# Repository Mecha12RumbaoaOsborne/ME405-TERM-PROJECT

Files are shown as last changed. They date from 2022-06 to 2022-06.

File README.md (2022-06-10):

# ME405-TERM-PROJECT
This repository contains the project files, source code, and other documents produced as part of the Polar Plotter project conducted 
by Ruodolf Rumbaoa and Barret Osborne. This project was done as part of the ME405 Mechatronics class for Cal Poly San Luis Obispo. The 
code included in this repository is ran on a NucleoL476RG that interfaces with two TMC4210 and two TMC2208 stepper drivers to control
two 4-wire NEMA 17 stepper motors. The baord also interfaces with a DC motor to control pen up/pen down functionality. 

One of the NEMA 17 steppers mount on a 3D printed structure that is mounted on a white board and a piece of 3/4 plywood. This stepper is
used to drvie the revolute motion of the plotter arm. The second stepper is used to drive the translation along the plotter's arm using a
belt and pulley system. The pen and DC motor are mounted on the arm and translates when the belt is driven by the second stepper motor. 
The arm sits on a lazy susan bearing. A wheel is also connected to the end of the arm to provide additional support. 

The TMC4210 driver class file is used to control the position or velocity of the steppers and can be
used for different functions like, enable/disable, position/velocity reading, taget position/velocity setting, zeroing, and homing. The
main routine uses a shceduler provided by the instructor of the class to run the tasks necessary to interpret an hpgl file stored in
board memory and draw it on a white board. Inkscape was used to generate an hpgl file from desired image files. When the main routine
is ran, the plotter waits for a button input to begin using the scheduler to parse the hpgl files for instructions and coordinates
which are then sent to the steppers as integer theta inputs. The plotter then draws the image point by point until it finishes. Finally,
when the drawing is finished the motors home to their original states. 

Demo Video:

ME405 DEMO (http://www.youtube.com/watch?v=i4va4gdoDfE "ME405 POLAR PLOTTER DEMO")

Documentation Page: [ME405 Polar Plotter Documentation](https://mecha12rumbaoaosborne.github.io/mecha12.github.io/)

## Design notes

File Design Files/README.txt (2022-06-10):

This folder contains all the mechanical design files for the polar plotter. These CAD files were made on SolidWorks 2022.

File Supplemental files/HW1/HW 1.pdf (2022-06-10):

Memorandum
To: Charlie Refvem
From: Ruodolf Rumbaoa
Date: 4/21/22

For the term project our driver must be able to interface with the TMC4210 and TMC2208 ICs to function properly with the stepper motor. Our drivers will need to have the functionality of enabling the TMC2208, setting velocity and acceleration on the TMC4210, setting a target position of the stepper through the TMC4210, and setting or reading the actual position of the stepper through TMC4210. These methods are laid out in the following class diagram.

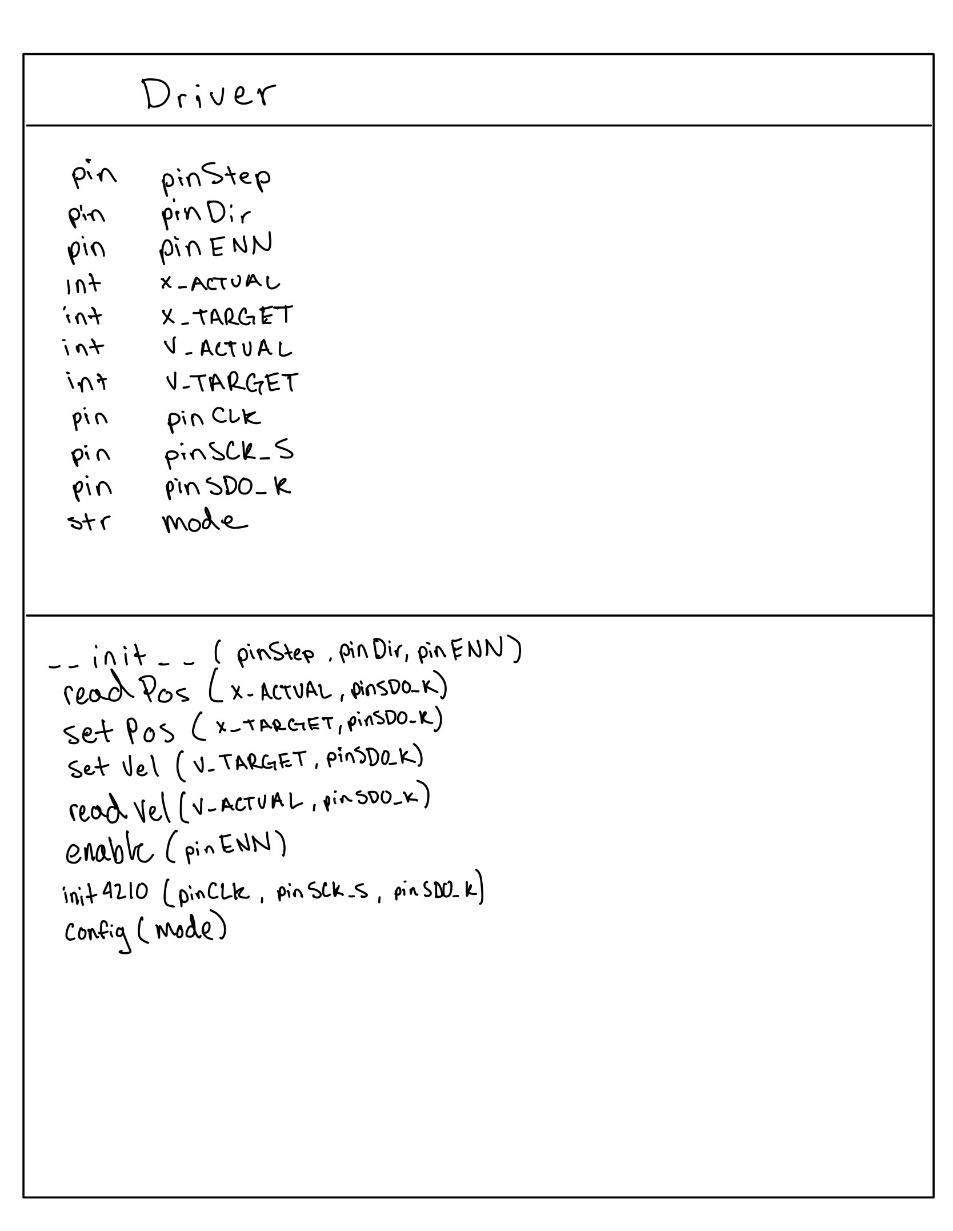
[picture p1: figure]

Figure 1. Driver class Diagram

To perform these methods, we must use the register map to either read or write to the corresponding register. To enable the TMC2208, we plan on connecting the EN1 and EN2 pins for the two TMC2208 drives to PC0 and PC1 on the Nucleo-L476RG, so that we can toggle them. These are read as active low, so we have to toggle the pin low to enable the TMC2208. To initialize the TMC4210 we write to the IF_CONFIGURATION_4210 address. Setting velocity will be done by writing to V_TARGET. Setting acceleration will be done by writing to A_MAX. To set a target position we will write to X_TARGET. Finally, to read the actual position of the stepper, we read from X_ACTUAL. We may also make use of limit switches to indicate the position of the stepper but have not figured out how to do that yet.

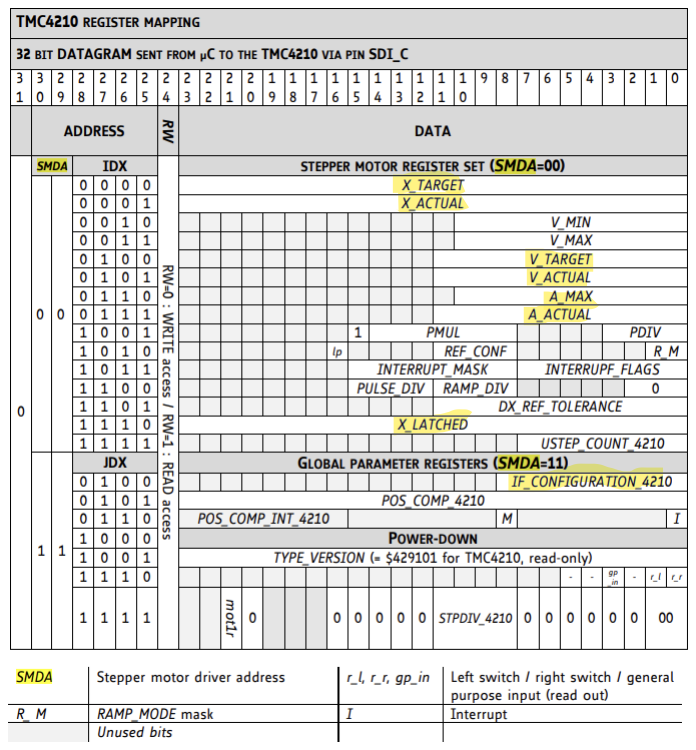
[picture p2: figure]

Figure 2. Register map for the TMC4210

The following table will include our initial plan for pin connections for the drivers with the Nucleo-L476RG. Most of the pins will be standard GPIOs while the MOSI, MISO, and SCK will be configured to a more dedicated pin.
Table 1. Preliminary pin configuration
MCU Pin | Function
PB_6 | CLK
PC2 | CS1
PC3 | CS2
PA_5 | SCK
PA_6 | MOSI
PA_7 | MISO
PC0 | EN1
PB4 | INDEX1
PC1 | EN2
PB5 | INDEX2
GND | GND
3V3 | +3.3V

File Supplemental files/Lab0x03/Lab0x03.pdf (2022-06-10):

### Memorandum

To: Charlie Refvem
From: Barrett Osborne, Ruodolf Rumbaoa
Date: 5/25/2021

For Lab 0x03, our task was to generate an HPGL file using Inkscape, save the file as a text file, and parse the contents of the text file. Our implementation began by separating the large string within the text file by semi-colons using split (‘;’). This resulted in a list of lists containing the strings of instructions and coordinates.

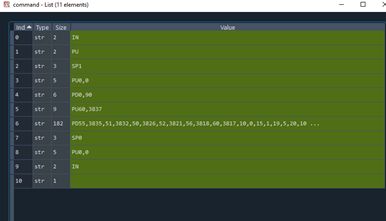
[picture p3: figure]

Figure 1. Data split by semi colons To interpret the instructions (pen up or pen down) we iterated through, looking at the first two characters of each element. By doing this we could interpret the instructions generated by Inkscape. We then stripped these instruction characters to generate an array of all the coordinates to be processed through our Newton Raphson code from HW2.

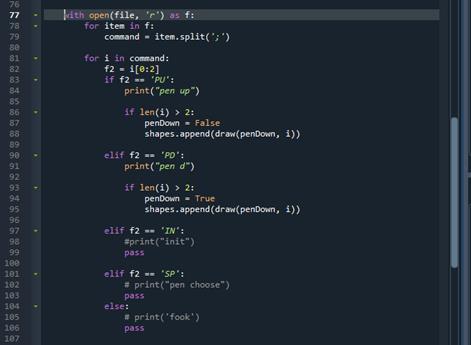
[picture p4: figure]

Figure 2. Instruction interpretation code snippet

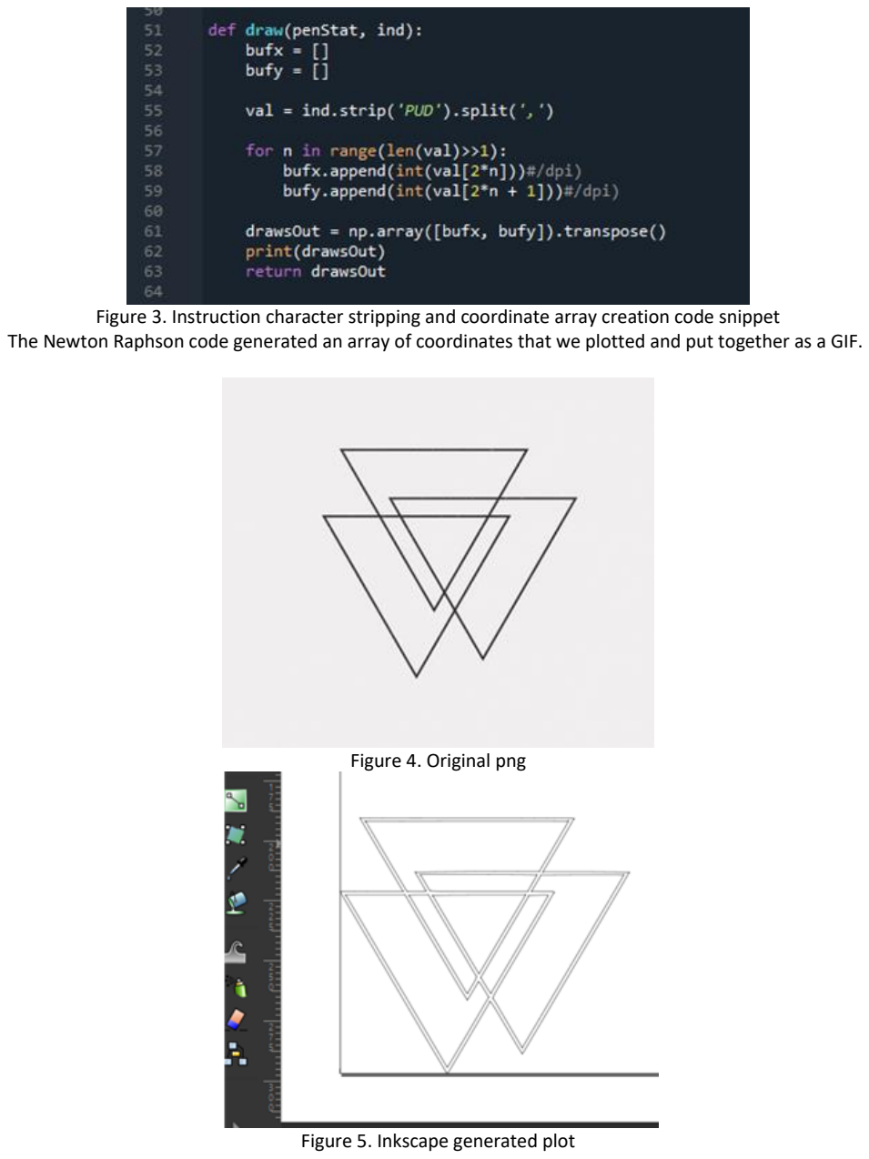
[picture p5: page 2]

Figure 3. Instruction character stripping and coordinate array creation code snippet The Newton Raphson code generated an array of coordinates that we plotted and put together as a GIF.

Figure 4. Original png

Figure 5. Inkscape generated plot

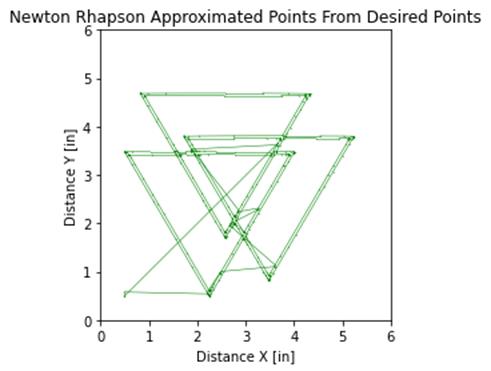
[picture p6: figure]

Figure 6. Plot generated from Newton Raphson code. NOTE: this plot and GIF shows the position of the end effector and doesn’t show the pen lifting or going down

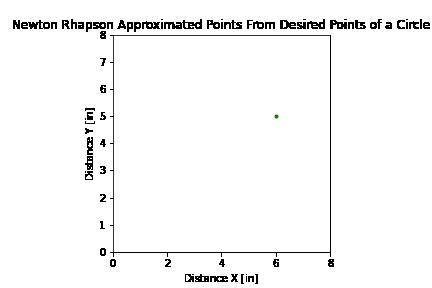
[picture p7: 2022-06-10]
Supplemental files/HW2/CirclePlot.gif

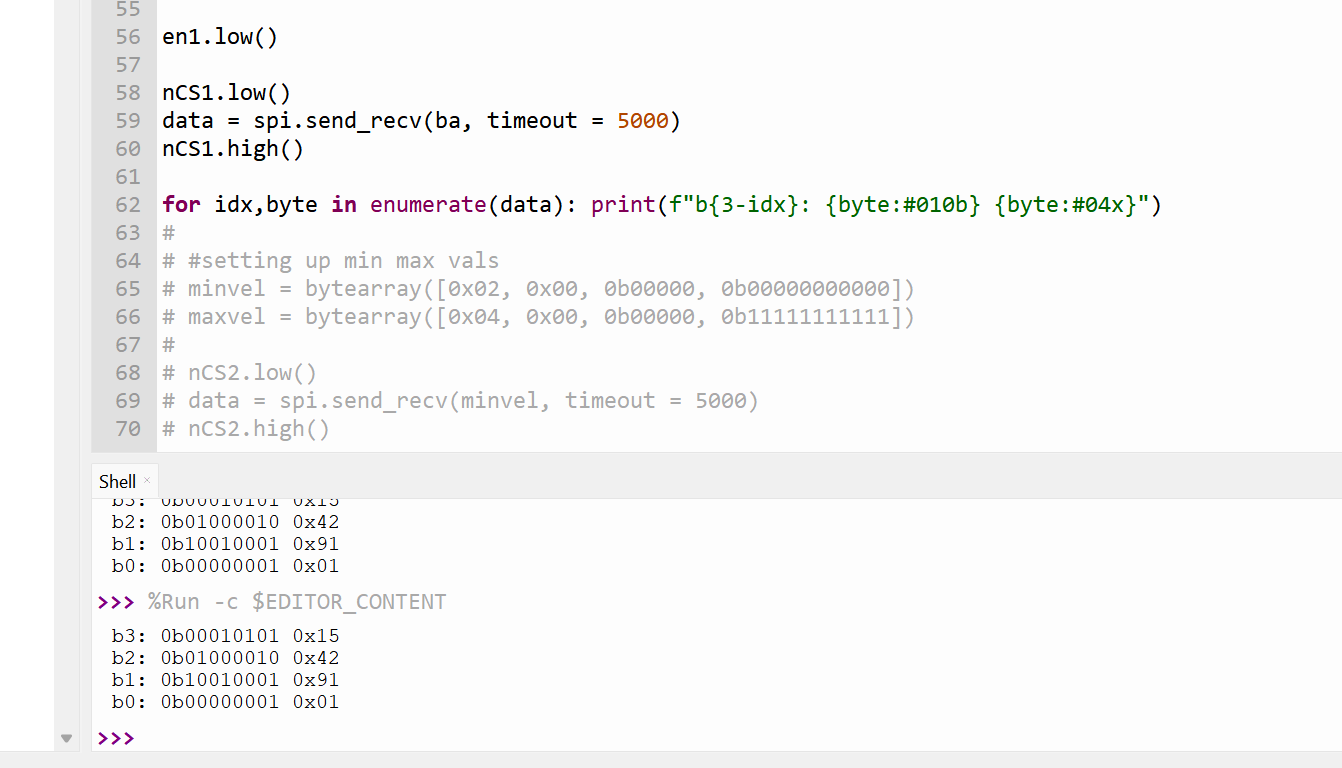
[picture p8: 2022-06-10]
Supplemental files/Lab0x02/typeregreadout.png

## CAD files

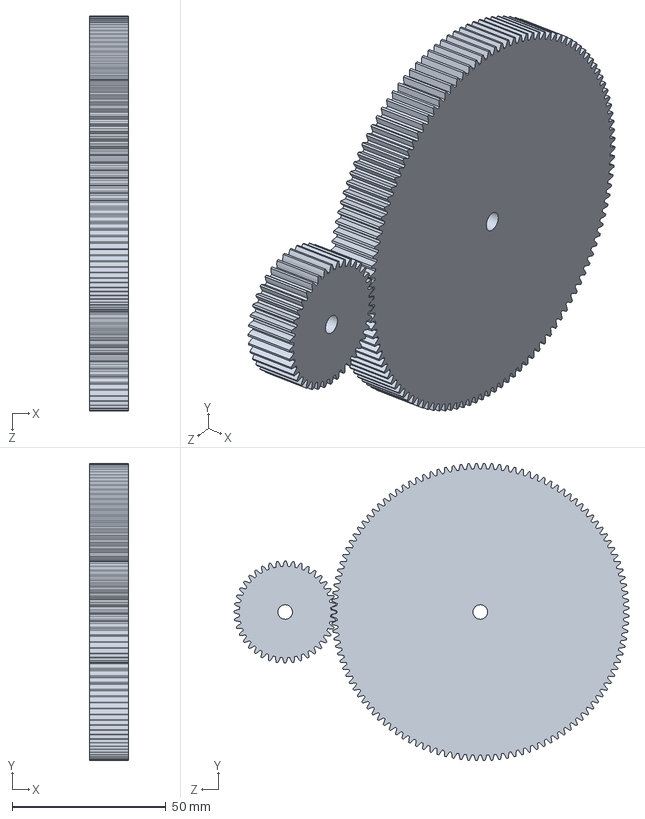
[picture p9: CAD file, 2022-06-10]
Design Files/Gears.SLDASM
12.7 x 96.8 x 128.6 mm
spur gear_ai x 2

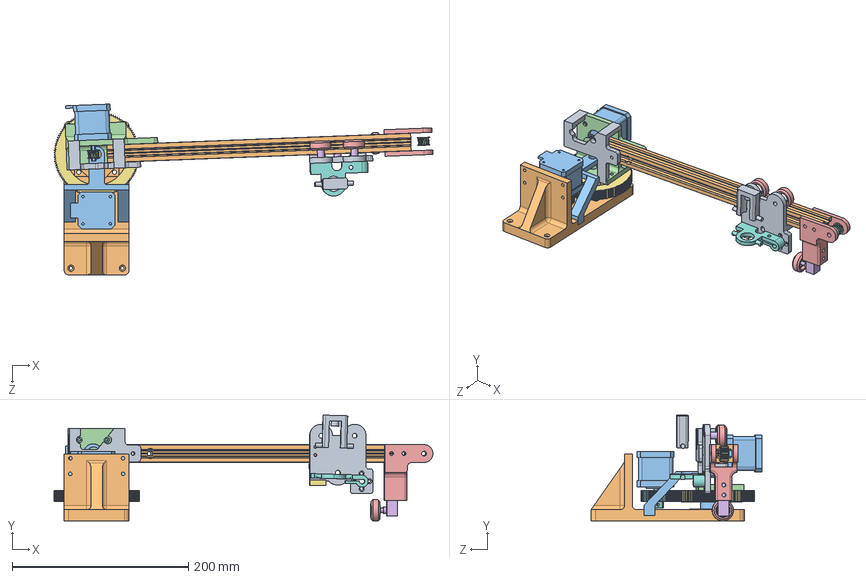
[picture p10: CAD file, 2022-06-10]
Design Files/Project Assembly.SLDASM
430.0 x 120.1 x 193.9 mm
Carriage Plate
2020 profile
40-42 motor x 2
2GT-pulley x 2
Rollers x 4
Spacers for rollers x 3
Hard Stop
PenArmNew
Motor box cageSLDPRT
baseplate without axel guard
BaseArm gaurd
Motor Box to go with cage bearing
NEW END BEAM
EndPlate Bearing
SpurGearBig
SmallGear2
SpringEnd
Bearingtop x 2
BearingCenter

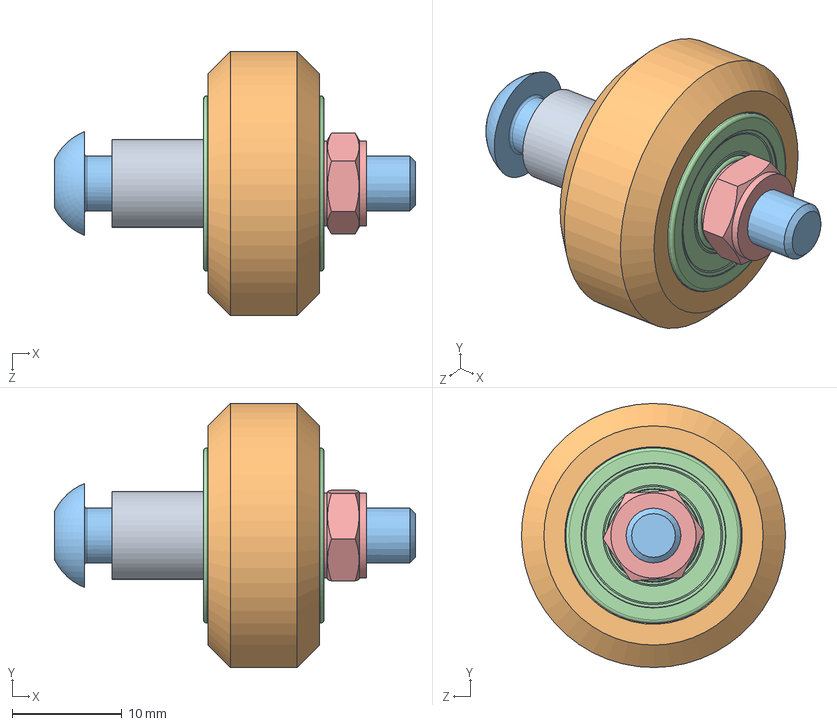
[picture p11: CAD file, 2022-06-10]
Design Files/ASM Roller X-Axis.SLDASM
33.0 x 24.1 x 24.1 mm
Spacers for rollers
Rollers
M5X30 Pan Head Screw
625pillow x 2
M5 Self-locking nut

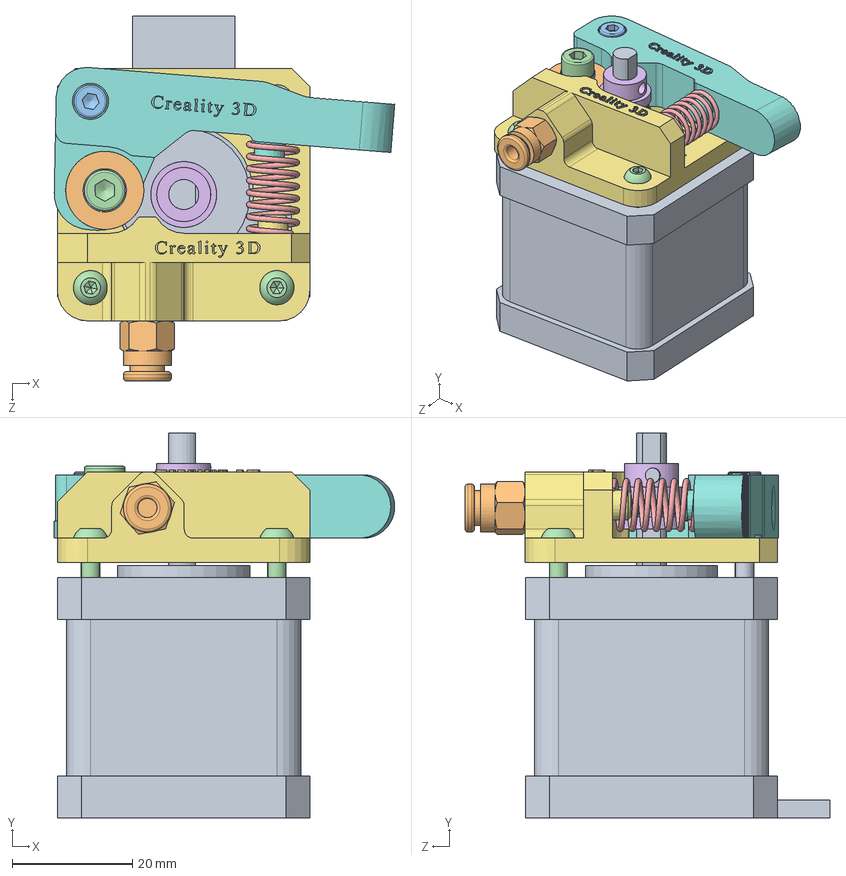
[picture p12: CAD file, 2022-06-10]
Design Files/ASM Extruder.SLDASM
56.7 x 64.0 x 60.7 mm
40-42 motor
624U pillow
M3X18 Socket Head Screw
M3X10 Pan Head Screw x 2
Extrusion Spring
E gear
E housing 2
E idler tensioner
M3X10 Flush Head Screw
M6 Pneumatic joint
M4 Split Washer
M4X8 Socket Head Screw

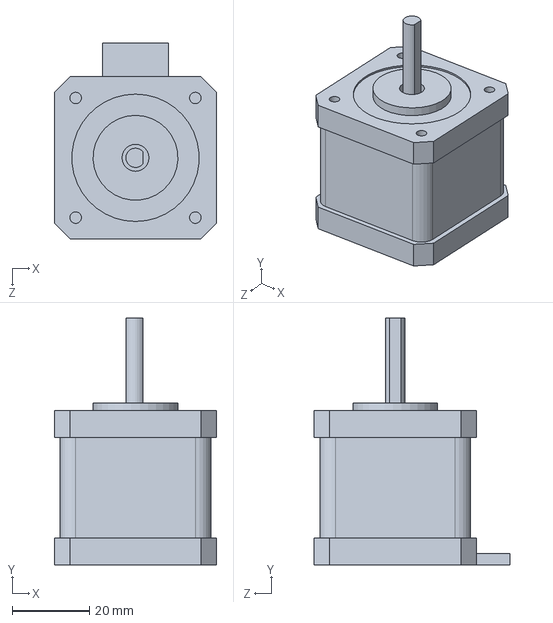
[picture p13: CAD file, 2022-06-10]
Design Files/40-42 motor.SLDPRT
42.0 x 64.0 x 50.7 mm

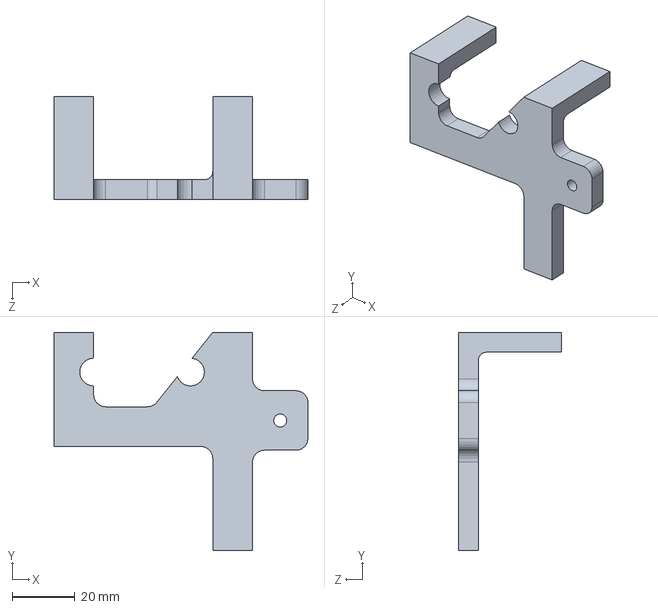
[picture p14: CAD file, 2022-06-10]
Design Files/Motor box cageSLDPRT.SLDPRT
81.3 x 69.8 x 32.9 mm

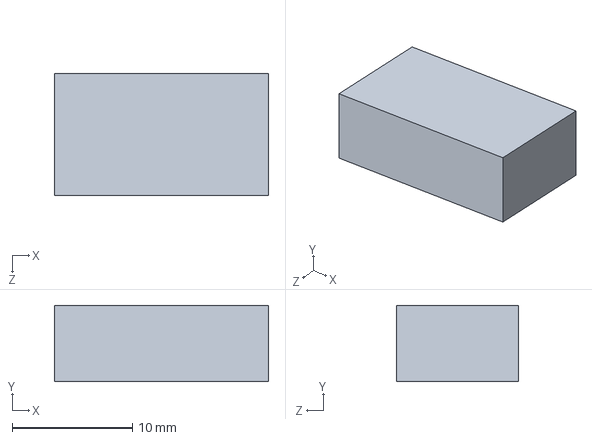
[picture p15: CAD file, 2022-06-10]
Design Files/Hard Stop.SLDPRT
17.8 x 6.35 x 10.2 mm

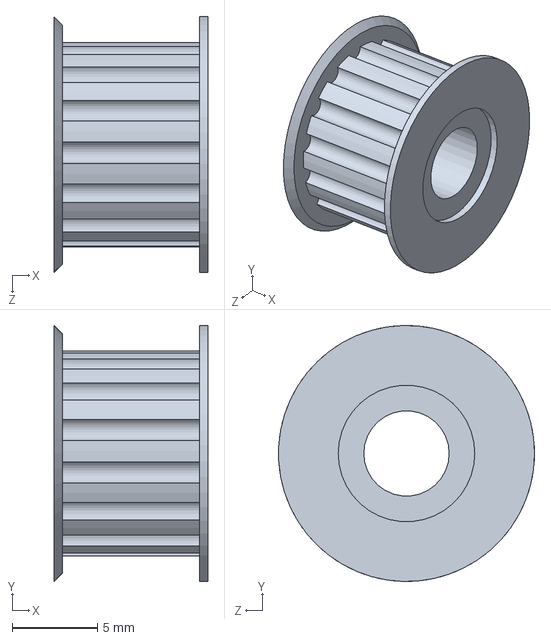
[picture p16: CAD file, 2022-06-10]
Design Files/2GT-pulley.SLDPRT
9.00 x 15.0 x 15.0 mm

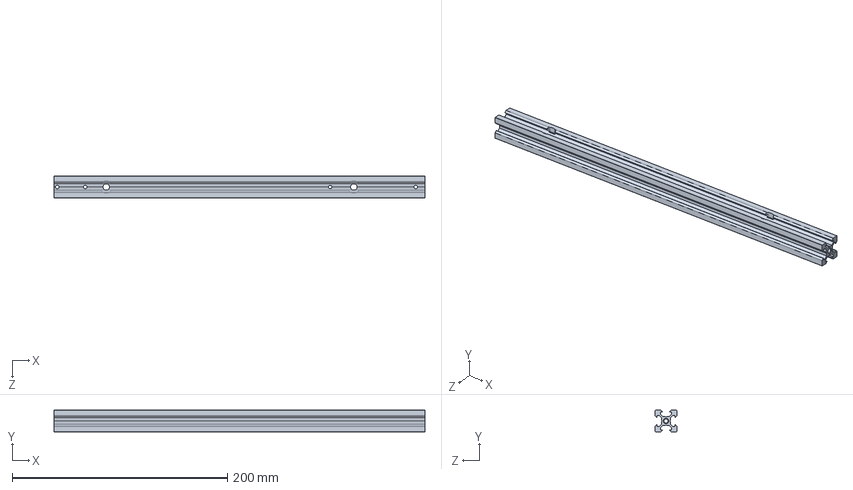
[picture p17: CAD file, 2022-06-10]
Design Files/2020 profile.SLDPRT
345.0 x 20.0 x 20.0 mm

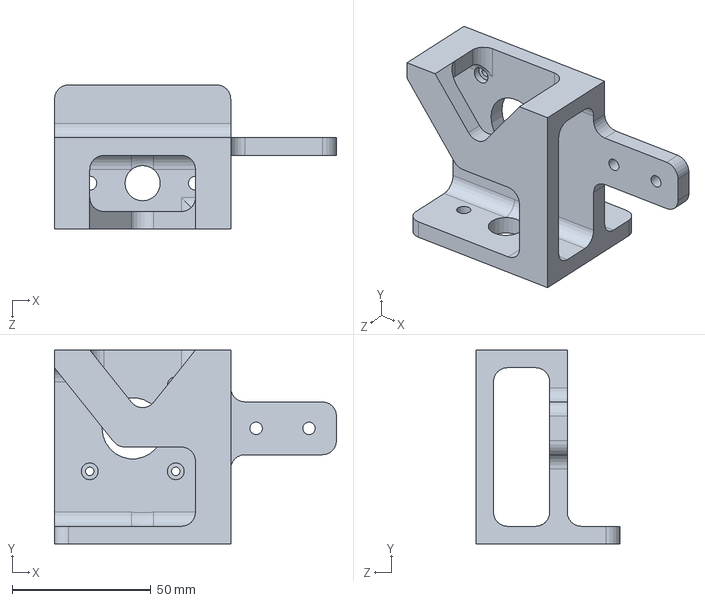
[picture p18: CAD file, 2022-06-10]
Design Files/Motor Box1.SLDPRT
101.6 x 69.8 x 52.0 mm

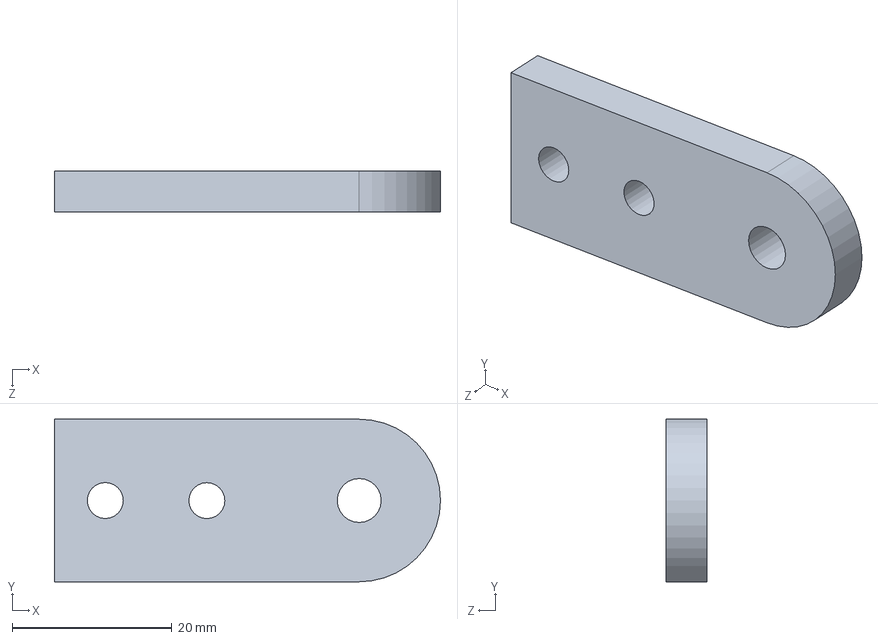
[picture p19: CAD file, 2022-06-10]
Design Files/End Plate.SLDPRT
48.3 x 20.3 x 5.08 mm

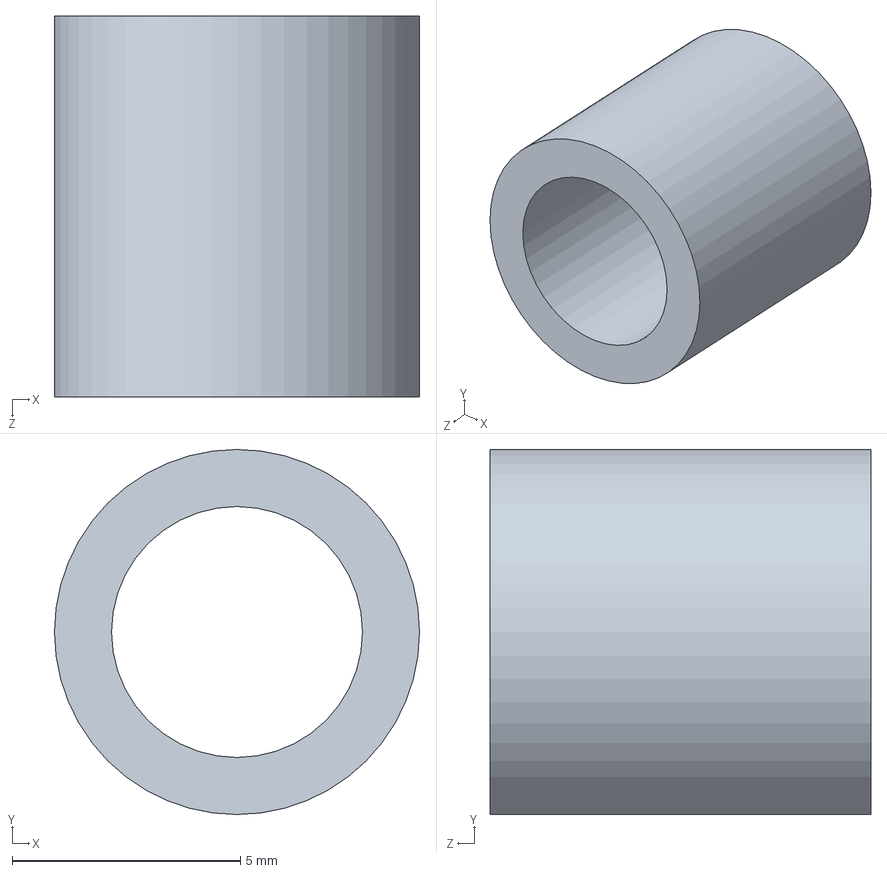
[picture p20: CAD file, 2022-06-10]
Design Files/Spacers for rollers.SLDPRT
8.00 x 8.00 x 8.35 mm

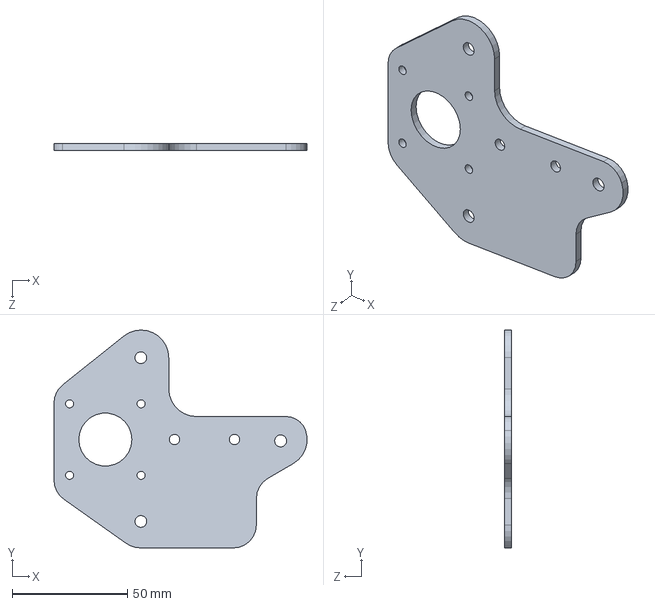
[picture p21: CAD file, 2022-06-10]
Design Files/X motor bracket.SLDPRT
109.7 x 94.5 x 3.00 mm

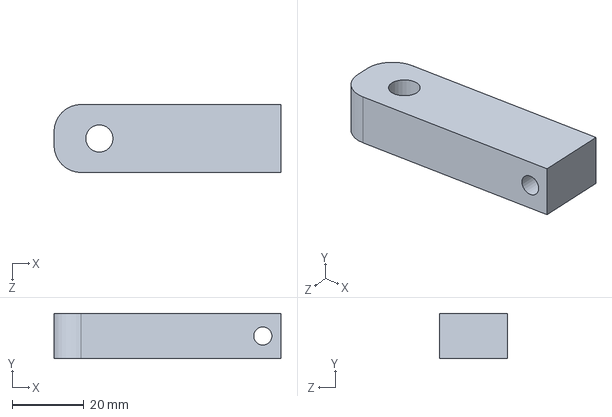
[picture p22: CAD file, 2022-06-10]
Design Files/Pen Arm.SLDPRT
63.5 x 12.7 x 19.1 mm

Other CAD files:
Design Files/PenArmNew.SLDPRT
Design Files/Radial Gearbox.SLDPRT
Design Files/Rollers.SLDPRT
Design Files/Motor Box to go with cage bearing.SLDPRT
Design Files/2020-2 profile.SLDPRT
Design Files/ASM X-Roller Bolt.SLDASM
Design Files/BaseArm gaurd.SLDPRT
Design Files/Baseplate spacer.SLDPRT
Design Files/BearingCenter.SLDPRT
Design Files/Bearingtop.SLDPRT
Design Files/Carriage Plate unbent.SLDPRT
Design Files/Carriage Plate.SLDPRT
Design Files/DrivenGearWithHoles.SLDPRT
Design Files/DrivingGear.SLDPRT
Design Files/E plate.SLDPRT
Design Files/End Plate 2.SLDPRT
Design Files/EndPlate Bearing.SLDPRT
Design Files/Gear1 hub.SLDPRT
Design Files/Gear2 hub.SLDPRT
Design Files/Motor Box to go with cage.SLDPRT
Design Files/Motor Box.SLDPRT
Design Files/NEW END BEAM.SLDPRT
Design Files/Roller bushing.SLDPRT
Design Files/SmallGear.SLDPRT
Design Files/SmallGear2.SLDPRT
Design Files/Spring Pegs.SLDPRT
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

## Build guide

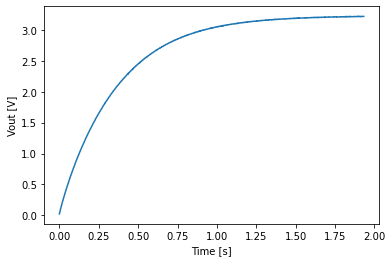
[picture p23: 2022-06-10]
Supplemental files/Lab0x00/5 working mostly/step response plot.png

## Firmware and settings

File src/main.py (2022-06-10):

"""!@file main.py
@brief      Main file for polar plotter project.
@n
@page mainroutine  main.py
@brief      This main routine makes use of the provided scheduler to run the parsing
            of an hpgl file saved in baord memory, and sending insturctions(pen up/down)
            and coordinates to the plotter.
@details    When ran, the main routine waits for the user to press the blue button on the 
            NucleoL476RG board. Once this press is detected, the scheduler runs the parsing
            and drawing task to extract instructions and coordinates from the hpgl file.
            The instructions are interpreted as pen up/down and the DC motor actuates
            according to it. The xy coordinates are converted to theta 1 and theta 2 values
            sento to the repective stepper. Once the task finishes a flag is raised and 
            the steppers go back to home position. 
@n     
Source Folder
    [https://github.com/Mecha12RumbaoaOsborne/ME405-TERM-PROJECT]
@n

@author Barret Osborne
@author Ruodolf Rumbaoa
@date 06/09/2022

"""
from ulab import numpy as np
#import numpy as np
import cotask, task_share, gc, array
from time import sleep
from math import cos, sin, pi, tan, sqrt, acos, asin, atan2
from pyb import SPI, Pin, Timer, ExtInt, UART
from TMC4210 import TMC4210drv

def onButtonpress(IRQ_src):
    '''
    @breif Button flag used to start the drawing task
    '''
    buttonFlag.put(1)
    
def g(x, theta, r):
    '''
    @breif Calculates motor thetas from xy coordinate inputs
    '''
    g1 = x[0]-r*theta[1]*float(cos(theta[0])) 
    g2 = x[1]-r*theta[1]*float(sin(theta[0]))
    return np.array([g1, g2])

def dg_dtheta(theta, r):
    '''
    @breif Calculates the jacobian
    '''
    return np.array([[r*theta[1]*float(sin(theta[0])), -r*float(cos(theta[0]))],
                            [-r*theta[1]*float(cos(theta[0])), -r*float(sin(theta[0]))]]) 

def NewtonRaphson (fcn, jacobian, guess, thresh):
    '''
    @breif Calculates the new thetas approximated by NewtonRaphson method
    '''
    new_theta = guess - (np.dot(np.linalg.inv(jacobian),fcn))
    return new_theta

def iterate(fcn, x, theta, r, thresh):
    '''
    @breif Used to iteratively call NewtoRaphson method to find motor thetas
    '''
    while True:
        newTheta = fcn(g(x, theta, r), dg_dtheta(theta, r), theta, thresh)
        gtheta = g(x, theta, r)
    
        if np.linalg.norm(gtheta) > thresh:
            theta = newTheta
            continue
        else:
            correct_theta = newTheta
            break
    return correct_theta

def parse(file):
    '''
    @breif Opens the hpgl file defined and extracts pen up/down instructions
           and xy coordinates of each point
    @param file The hpgl file to be prsed
    '''
    with open(file, 'r') as f:
        for item in f:
            command = item.split(';')
        for i in command:
            f2 = i[0:2]
            if f2 == 'PU':
                if len(i) > 2:
                    shapes.append(extract(i))
            elif f2 == 'PD':
                if len(i) > 2:
                    shapes.append(extract(i))
            else:
                pass
            f.close() 
            shapesInst = shapes
    return shapesInst

def extract(insts):
    '''
    @breif Splits extracted instructions by commas to generate xy coordinates
    @param insts Instructions extracted from parsed file
    '''
    instOut = []
    val = insts.split(',')

    for n in range(len(val)>>1):    
       instOut.append([val[2*n], val[2*n+1]])
       

    return instOut

def drawTask ():
    '''
    @breif Calls the draw function and sets flag to represent when drawing is finished
    '''
    while True:
        print('DRAWING')
        xcoordData.clear()
        ycoordData.clear()
        instructions = parse(file)
        for point in instructions:
            draw(point) 
        drawingDone.put(1)
        buttonFlag.put(0)
        state == 0
        break
    yield state
        
def draw(instVal):
    '''
    @breif Uses the extracted xy coordinates to calculate motor thetas. Then sends
           motor thetas to respective stepper. Also interprets pen instructions to 
           actuate DC motor.
    '''
    inst = instVal[0]
    k=0
    if inst[0][0:2] == 'PU':
        print('pen up')
        PB5.low()
        PB4.high()
        sleep(.8)
        
        
        instVal[0][0] = instVal[0][0].strip('PU')
        
        #Construct as a share later 0 = up 1 = down 
        penShare = 0
        
        while k < len(instVal):
            incoordx = 1.5*((int(instVal[k][0])+100)/dpi)
            incoordy = 1*((int(instVal[k][1])+1)/dpi)
            xcoordData.put(incoordx)
            ycoordData.put(incoordy)
            uart2.write(f'{xcoordData.get()}, {ycoordData.get()}\r\n')
            hyp = sqrt(incoordx**2 + incoordy**2)
            
            thetas = np.array([1*(atan2(incoordy,incoordx)), hyp/inrad])
            
            usteps1 = int(thetas[0]*3600/(2*pi))
            usteps2 = int(thetas[1]*400/(2*pi))
            print(f'[{usteps1}, {usteps2}]')
            
            while True:
                stepthresh = 1
                drv1.setPos(usteps1)
                drv2.setPos(usteps2)
                sleep(.25)
                comp1 = usteps1
                comp2 = usteps2
                act1 = drv1.getPos()
                act2 = drv2.getPos()
                
                if (abs(comp1 - act1) < stepthresh) and (abs(comp2 - act2 < stepthresh)):
                    break

                else:
                    pass
                    
            k+=1
            continue
            
        
    elif inst[0][0:2] == 'PD':
        print('pen down')
        PB4.low()
        PB5.high()
        instVal[0][0] = instVal[0][0].strip('PD')
        
        #Construct as a share later 0 = up 1 = down 
        penShare = 1
        
        while k < len(instVal):
            incoordx = 1.5*((int(instVal[k][0])+100)/dpi)
            incoordy = 1*((int(instVal[k][1])+1)/dpi)
            xcoordData.put(incoordx)
            ycoordData.put(incoordy)
            uart2.write(f'{xcoordData.get()}, {ycoordData.get()}\r\n')

            hyp = sqrt(incoordx**2 + incoordy**2)
            
            thetas = np.array([1*(atan2(incoordy,incoordx)), hyp/inrad])
            
            usteps1 = int(thetas[0]*3600/(2*pi))
            usteps2 = int(thetas[1]*400/(2*pi))
            print(f'[{usteps1}, {usteps2}]')

            while True:
                stepthresh = 1
                drv1.setPos(usteps1)
                drv2.setPos(usteps2)
                sleep(.25)
                comp1 = usteps1
                comp2 = usteps2
                act1 = drv1.getPos()
                act2 = drv2.getPos()
                
                if (abs(comp1 - act1) < stepthresh) and (abs(comp2 - act2 < stepthresh)):
                    break

                else:
                    pass
            k+=1
            continue
            

    else:
        while k < len(instVal):
            incoordx = .7*((int(instVal[k][0])+100)/dpi)
            incoordy = 1*((int(instVal[k][1])+1)/dpi)
            xcoordData.put(incoordx)
            ycoordData.put(incoordy)
            uart2.write(f'{xcoordData.get()}, {ycoordData.get()}\r\n')
            hyp = sqrt(incoordx**2 + incoordy**2)

            thetas = np.array([1*(atan2(incoordy,incoordx)), hyp/inrad])
            
            usteps1 = int(thetas[0]*3600/(2*pi))
            usteps2 = int(thetas[1]*400/(2*pi))
            print(f'[{usteps1}, {usteps2}]')
            
            while True:
                stepthresh = 1
                drv1.setPos(usteps1)
                drv2.setPos(usteps2)
                sleep(.25)
                comp1 = usteps1
                comp2 = usteps2
                act1 = drv1.getPos()
                act2 = drv2.getPos()
                
                if (abs(comp1 - act1) < stepthresh) and (abs(comp2 - act2 < stepthresh)):
                    break
                    #sleep(.5)
                    pass

                else:
                    pass
            k+=1
            continue
    
    pass
if __name__ =='__main__':    
    state = 0 #INIT AND WAIT STATE
    
    #Limit switch pen up/down
    PC4 = Pin(Pin.cpu.C4, mode=Pin.OUT_PP, value=0)
    PB4 = Pin(Pin.cpu.B4, mode=Pin.OUT_PP, value=0)
    PB5 = Pin(Pin.cpu.B5, mode=Pin.OUT_PP, value=0)

    
    # Motor stuff
    drv1 = TMC4210drv(2, SPI.SLAVE, 1_000_000, 1, 1, None, Pin(Pin.cpu.C3, mode=Pin.OUT_PP, value =1), 4, 1, Pin(Pin.cpu.B6, mode = Pin.OUT_PP), Pin(Pin.cpu.C2, mode=Pin.OUT_PP, value =1))
    drv2 = TMC4210drv(2, SPI.SLAVE, 1_000_000, 1, 1, None, Pin(Pin.cpu.B0, mode=Pin.OUT_PP, value =1), 4, 1, Pin(Pin.cpu.B7, mode = Pin.OUT_PP), Pin(Pin.cpu.C0, mode=Pin.OUT_PP, value =1))
    
    uC = SPI(2)
    uC.init(SPI.MASTER, baudrate=1_000_000, phase=1, polarity=1, crc=None)
    
    #Set ensd to 1 for both drivers
    drv1.enable()
    drv2.enable()
   
    drv1.setRampmode()
    drv2.setRampmode()
    
    #Set VMIN
    drv1.setMinVel(0b00000000001)
    drv2.setMinVel(0b00000000001)
    
    #Set VMAX
    drv1.setMaxVel(0b00000000001)
    drv2.setMaxVel(0b00000000001)
    
    #Set Pulse div and ramp div
    drv1.setPulseramppulsediv(0b0000, 0b0000)
    drv2.setPulseramppulsediv(0b0000, 0b0000)
    
    #Set AMAX
    drv1.setMaxAcc(0b00000111,0b11010000)
    drv2.setMaxAcc(0b00000111,0b11010000)

    #Set PDIV 1 and PMUL 249
    drv1.setPMULPDIV(0b11111001, 0b0000001)
    drv2.setPMULPDIV(0b11111001, 0b0000001)
    
    #Start calib
    drv1.zeroHere()
    drv2.zeroHere()
    
    #UART Stuff
    uart2 = UART(2)
    uart2.init(115200, bits=8, parity=None, stop=1)
    
    #NewtonRaphson params
    theta_guess = np.array([5,6])
    thresh = 1e-6
    r = 0.24
    inrad = r/(pi*2)
    
    #HPGL params
    shapes = []
    
    #Name the file to be parsed and drawn, specify dpi set from Inkscape. Increaseing or decreasing
    #will change the actual size of drawing on the baord 
    file = "susamongus.hpgl"
    dpi = 240
    
    # Coop task shares and queues
    
    #used as a flag for knowing when the drawing task has finished
    drawingDone = task_share.Share ('i', thread_protect = False, name = "drawingDone")
    
    #Making use of the button on the Nucleo board to start the drawing task when pressed
    button_int = ExtInt(Pin.cpu.C13, ExtInt.IRQ_FALLING, Pin.PULL_NONE, None)
    button_int = ExtInt(Pin.cpu.C13, ExtInt.IRQ_FALLING, Pin.PULL_NONE, callback=onButtonpress)
    buttonFlag = task_share.Share ('i', thread_protect = False, name = "buttonFlag")
    
    #Set as 0 initially 
    buttonFlag.put(0)
    drawingDone.put(0)
    
    #Creating tasks
    drawTask = cotask.Task(drawTask, name = 'Task_2', priority = 1, 
                         period = 50, profile = True, trace = False)
    
    #Appending task to task list to be ran by scheduler based on priority
    cotask.task_list.append(drawTask)
     
    xcoordData = task_share.Queue ('f', 300, thread_protect = True, overwrite = False,
                           name = "xcoordData")
    ycoordData = task_share.Queue ('f', 300, thread_protect = True, overwrite = False,
                           name = "ycoordData")
    
    #Memory cleaning before running
    gc.collect ()
    xcoordData.clear()
    ycoordData.clear()

    #Run tasks using cotask when button is pressed. Stops the run if interrupted using ctrl+c
    while True:
        try:
            if buttonFlag.get() == 1:
                cotask.task_list.pri_sched()
            elif drawingDone.get() == 1:
                xcoordData.clear()
                ycoordData.clear()
                drv1.disable()
                drv2.disable()
                break
                
            else:
                pass
            
        except KeyboardInterrupt:
            drv1.disable()
            drv2.disable()
            PB5.low()
            break
    
    #Once the task finishes the scheduler stops being used and the motors home back to zero
        
    drv1.goZero()
    drv2.goZero()
    
    sleep(5)
    drv1.disable()
    drv2.disable()
    print('motors disabled')

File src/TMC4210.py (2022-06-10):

"""!@file TMC4210.py
@brief      Class file for stepper drivers.
@n
@page driver  TMC4210.py
@brief      This class file contains the methods and attributes of the TMC4210 drivers.
@details    The file includes methods for setting target position/velocity, reading 
            position/velocity, writing to configuration adresses, and homing/zeroing
            the stepper motors.. 

Source Folder
    [https://github.com/Mecha12RumbaoaOsborne/ME405-TERM-PROJECT]
@n

@author Barret Osborne
@author Ruodolf Rumbaoa
@date 06/09/2022

"""
from pyb import SPI, Pin, Timer
import time

# Stepper Register Set
#X_TARGET and V_TARGET (1 byte size) are made as bytes to be concatenated
#with integer values that the user inputs which are then turned to
#bytes objects (3 bytes size) to create a proper 32 bit datagram.
#Other adresses are hex values inputed into a bytearray with specific
#binary data to configure devices. SEE  TMC4210 data sheet for register info.

X_TARGET             = (0x00).to_bytes(1, 'big')
X_ACTUAL             = 0x02
V_MIN                = 0x04
V_MAX                = 0x06
V_TARGET             = (0x08).to_bytes(1, 'big')
V_ACTUAL             = 0x0A
A_MAX                = 0x0C
A_ACTUAL             = 0x0E
PMUL_PDIV            = 0x12
RAMPMODE_REFCONF     = 0x14
INTERRUPT_MASK_FLAGS = 0x16
PULSE_DIV_RAMP_DIV   = 0x18
DX_REF_TOLERANCE     = 0x1A
X_LATCHED            = 0x1C
USTEP_COUNT_4210     = 0x1E

# Global Parameter regs
IF_CONFIGURATION_4210= 0x68
POS_COMP_4210        = 0x6A
POS_COMP_INT_4210    = 0x6C
POWER_DOWN           = 0x70
TYPE_VERSION         = 0x73
REFERENCE_SWITCHES   = 0x7C
GLOBAL_PARAMETERS    = 0x7E
# R = 1 W = 0

class TMC4210drv:
    
    def __init__(self, spi_num, spi_mode, spi_baud, spi_phase, spi_pol, spi_crc, ncsPin, clk_timer, clk_channel, clkPin, ENPin):
        '''
        @brief      Initializes the drviver objects.
        @details    The driver objects are initialized as SPI2 peripherals with 
                    pin objects for clock timer/channel and enable PIN.
        @param spi_num SPI bus to initialize the driver (using SPI2)
        @param spi_mode SPI.PERIPHERAL
        @param spi_baud Baudrate for SPI transmission (using 1_000_000).
        @param spi_phase spi_pol These parameters dictate the mode being ran (using mode 3)
        @param spi_crc None
        @param ncsPin Pin object used for chip select
        @param clk_timer Timer object being used by drivers
        @param clk_channel Timer channel
        @param clkPin Pin object being used for clock signal 
        @param ENPin Pin object used for EN
        '''
        #use spi(2)
        self.spi = SPI(spi_num)
        
        #use params: SPI.SLAVE, 1000000, 1, 1, None 
        self.spi.init(spi_mode, baudrate=spi_baud, phase=spi_phase, polarity=spi_pol, crc=spi_crc)
        
        #use C3 or B0 for CS pins
        self.nCS = Pin(ncsPin, mode = Pin.OUT_PP, value = 1)
        
        #use C2 or C0 for EN pins
        self.EN = Pin(ENPin, mode = Pin.OUT_PP, value = 0)
        
        #use Timer(4)
        self.clk = Timer(clk_timer)
        
        #20 mHz timer
        self.clk.init(prescaler = 0, period =3)
        
        # need PWM mode pin PB6 for clkPin
        self.clk.channel(clk_channel, mode=Timer.PWM, pin = clkPin, pulse_width = 2)
        
        pass
       
    def enable(self):
        '''
        @brief enables the stepper
        '''
        #Sets en_sd bit to 1
        enableba = bytearray([IF_CONFIGURATION_4210, 0x00, 0x00, 0x20])
        
        #Set enable pin low to activate power to motor
        self.EN.low()
        
        self.nCS.low()
        self.spi.send_recv(enableba, timeout=2000)
        self.nCS.high()
        print('The motor is enabled.')
        
        pass
    
    def setRampmode(self):
        '''
        @brief sets the driver to ramp mode. used for position control
        '''
        #Sets the driver to Ramp mode. Used for position control
        rampmode = bytearray([0x14, 0x00, 0x00, 0b00000000])
        
        self.nCS.low()
        self.spi.send_recv(rampmode, timeout=2000)
        self.nCS.high()
        
        pass
    
    def setVelmode(self):
        '''
        @brief sets the drivers to velocity mode. used for constant velocity control
        '''
        #Sets the driver to Velocity mode. Used for constant velocity applications
        velmode = bytearray([0x14, 0x00, 0x00, 0b00000010])
        
        self.nCS.low()
        self.spi.send_recv(velmode, timeout=2000)
        self.nCS.high()
        
        pass
    
    def setHoldmode(self):
        '''
        @breif sets the drvier to hold mode. used to overwrite actual position
               when writing to X_ACTUAL address
        '''
        #Sets the driver to Velocity mode. Used for constant velocity applications
        holdmode = bytearray([0x14, 0x00, 0x00, 0b00000011])
        
        self.nCS.low()
        self.spi.send_recv(holdmode, timeout=2000)
        self.nCS.high()
        
        pass
    def disable(self):
        '''
        @breif disables the motors
        '''
        #Set enable pin high to disable motor power
        self.EN.high()
        
        pass
    
    def getPos(self):
        '''
        @breif reads the position of the motor in microsteps
        '''
        #Read from X_ACTUAL address
        getPos = bytearray([0x03, 0x00, 0x00,0x00])
        
        self.nCS.low()
        self.data = self.spi.send_recv(getPos)
        self.nCS.high()
        
        self.intVal = int.from_bytes(self.data, 'big')-352321536
        
        return self.intVal
    
    def setPos(self, inputPos):
        '''
        @breif sets target position of stepper
        '''
        #Convert integer input to a bytes objects
        inputPos = (inputPos).to_bytes(3, 'big')

        #Write to X_TARGET 
        setPos = X_TARGET+inputPos
        
        self.nCS.low()
        self.data = self.spi.send_recv(setPos)
        self.nCS.high()
        
        pass
    
    def goZero(self):
        '''
        @breif writes X_TARGET to go to zero defined in beginning of main routine
        '''
        #Write to X_TARGET. Goes back to 0
        gozero = X_TARGET+bytearray([0b00000000, 0b00000000, 0b00000000])
        
        self.nCS.low()
        self.spi.send_recv(gozero)
        self.nCS.high()
        
        pass
    
    def zeroHere(self):
        '''
        @breif defines the zero position of stepper
        '''
        setZero = bytearray([X_ACTUAL, 0b00000000,0b00000000, 0b00000000])
        
        #Need to set to Velocity mode before overwrting X_ACTUAL
        self.setHoldmode()
        self.goZero()
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

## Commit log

2022-06-09 Code uploads
    Uploading the main and driver class for polar plotter
2022-06-10 adding CAD files to repo
    the CAD files include individual parts and full assembly
    [2020 profile.SLDPRT, 2020-2 profile.SLDPRT, 2GT-pulley.SLDPRT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]
